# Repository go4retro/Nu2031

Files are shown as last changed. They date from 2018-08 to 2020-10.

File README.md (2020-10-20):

# Nu2031 

This adapter allows one to utilize a Commodore 1541 disk drive as both a serial disk drive for the serial IEC-based Commodore computers (VIC-20, C64, +4, C16, C128, etc.) and also an IEEE-488 drive for the PET/CBM line of computer systems.

## Introduction

Nu2031 ("New" 2031, with new in quotes because it's not really new :-)) comprises a two part hardware modification for the Commodore 1541 disk drive.  The first part is a 6522 Versatile Interface Adapter (VIA) daughterboard that dynamically switches specific VIA signals between the existing 1541 serial IEC port and an on-board IEEE-488 interface. The second part is a special multi-bank ROM-el replacement ROM that contains both the original 1541 DOS and a patched DOS that will enable the 1541 drive to function as a IEEE-488 CBM 2031 workalike drive. Using a single switch, connected to both adapter boards, the system can be quickly switched from one interface to the other.

This design is a refinement of many previous conversion projects, listed below:

The original (and largest, in my opinion) effort was included in an old 64'er magazine article.  Andre Fachat, who built the original interface, re-created the schematic and re-typed in the DOS patching utility, which are available at  http://www.6502.org/users/andre/cbmhw/ieee488/index.html. 

Dirk Wouters improved on the design by allowing the conversion to be "switched off", allowing continued use of the 1541 as a 1541 drive while supporting the IEEE-488 functionality.  Though his plans are no longer available, the project is discussed at https://www.lemon64.com/forum/viewtopic.php?t=71124 and at https://www.forum64.de/index.php?thread/91569-1541-to-ieee488-trimod-adapter/ (German).

Nu2031 was started before Dirk's project was presented, so it does not borrow from that design, though the two projects share a common set of functionality.

## Technical Details

The heart of the unit is the main adapter PCB (the ROM board is just a simple multi-bank ROM). The PCB contains both the 75160 and 75161 IEEE-488 interface ICs, as well as a Xilinx XC9572XL Complex Programmable Logic Device (CPLD).  Unlike the initial 64'er/Andre Fachat project, which simply wired the VIC to the interface ICs, or Dirk Wouter's interface, which uses banks of quad bilateral CMOS 4066 bilateral switches to connect or disconnect the various VIA signals to the 1541 motherboard or the IEEE 488 bus transceivers, this design implements the various IEEE-488 signal directions, as noted on page 2 of the 75161B datasheet (https://www.ti.com/lit/gpn/sn75161b). For reference, DC is always 'H' (5V), so the truth table can be somewhat simplified. The  ROM select signal noth only chooses which ROM bank to use, but is also used by the design to select which interface to enable.  The deselected interface is configured to allow other devices to continue to function on the de-selected bus.

If the system sees the ROM select signal change state, the interface immediately reconfigures the interface connects and resets the drive so the correct ROM will be initialized.

## Future Directions:

- Support method to "softswitch" the interface from one bus to another.

## License
Copyright (C) 2019-20  RETRO Innovations

These files are free designs; you can redistribute them and/or modify
them under the terms of the Creative Commons Attribution-ShareAlike 
4.0 International License.

You should have received a copy of the license along with this
work. If not, see <http://creativecommons.org/licenses/by-sa/4.0/>.

These files are distributed in the hope that they will be useful,
but WITHOUT ANY WARRANTY; without even the implied warranty of
MERCHANTABILITY or FITNESS FOR A PARTICULAR PURPOSE.  See the
license for more details.

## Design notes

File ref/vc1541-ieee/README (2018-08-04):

This is the description of the IEEE488 interface published in the
German 64er magazin a long time ago. It is basically modelled
after the 2031 schematics, the IEEE488 sister drive to the VC1541.

Code to patch the VC1541 ROM is provided. The original 2031 ROM
is different in both ROM chips, but the patch manages to get the
changes into one ROM chip only.

A. Fachat

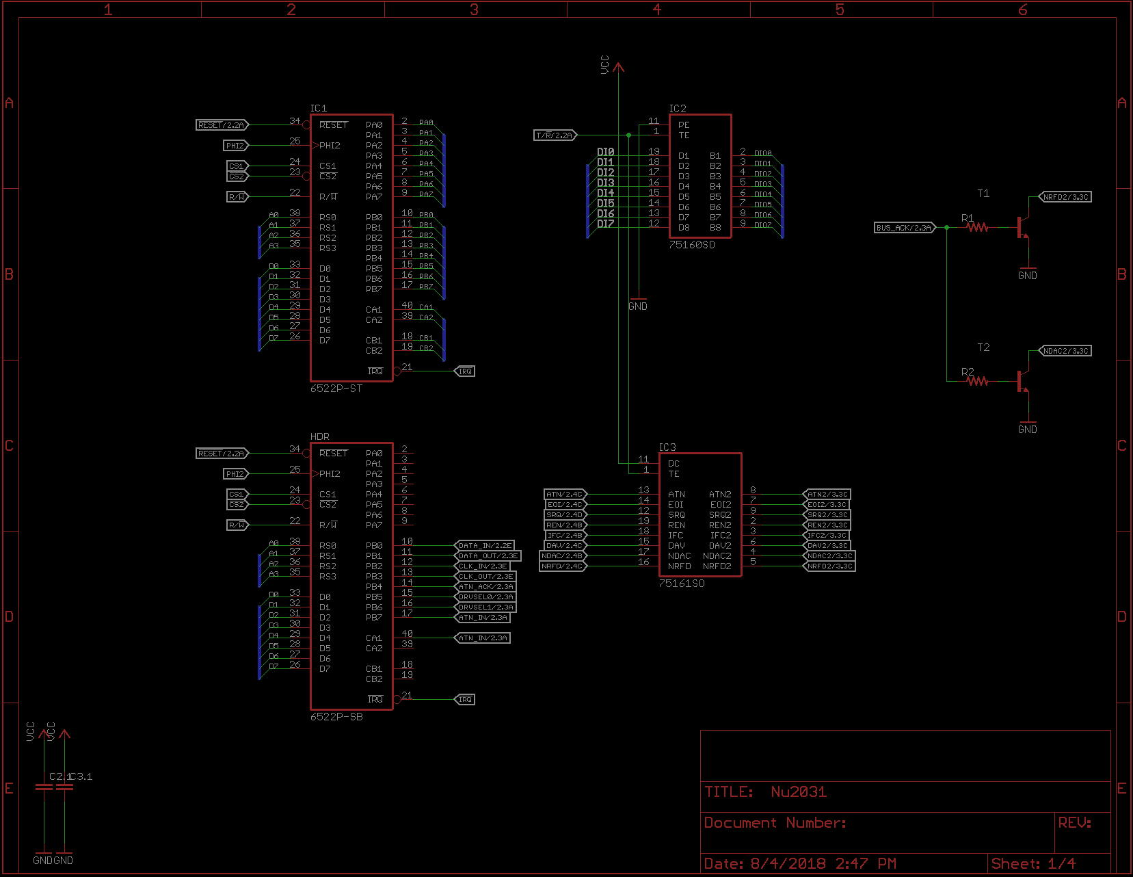
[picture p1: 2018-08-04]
pcb/Nu2031 Schematic.png

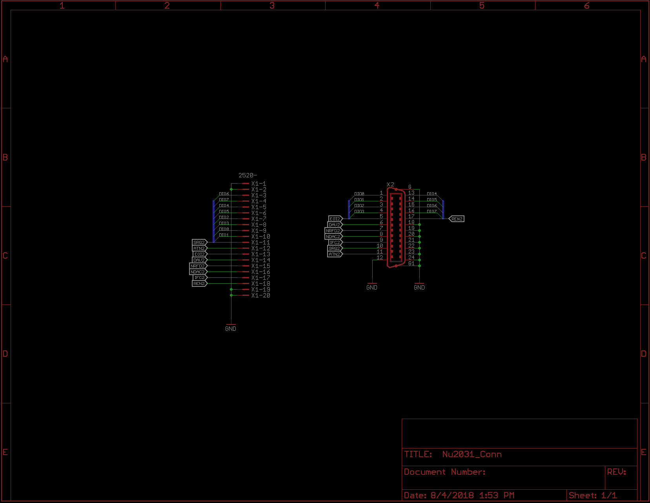
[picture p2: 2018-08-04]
pcb/Nu2031_Conn Schematic.png

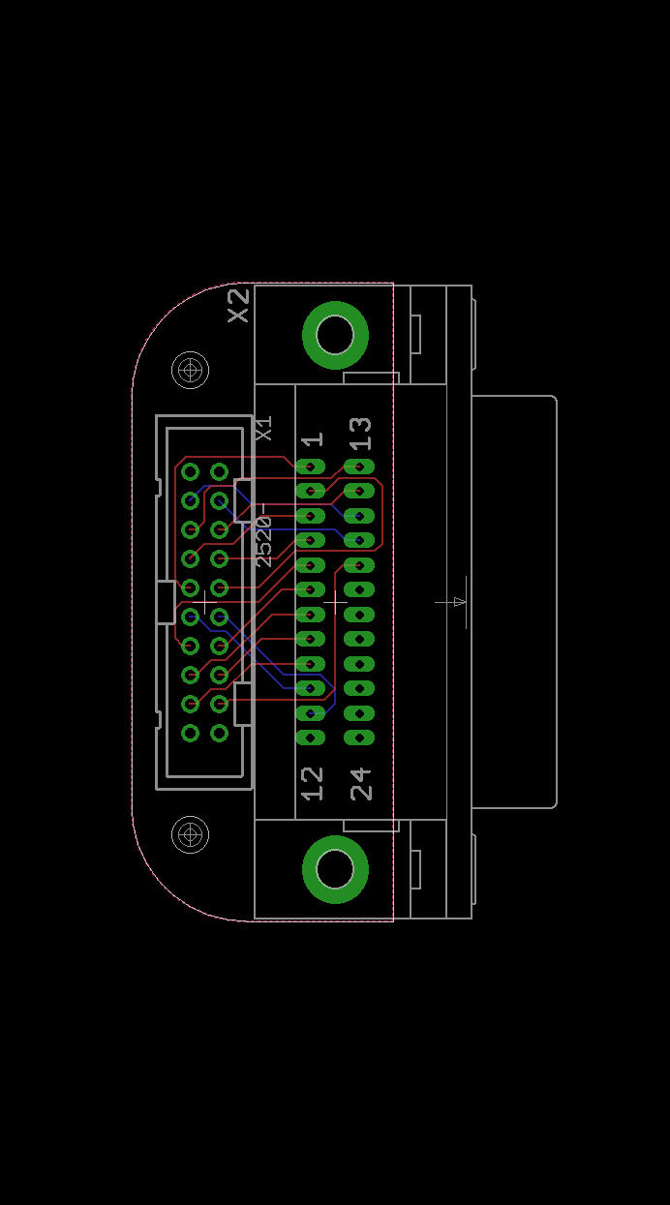
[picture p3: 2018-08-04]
pcb/Nu2031_Conn PCB.png

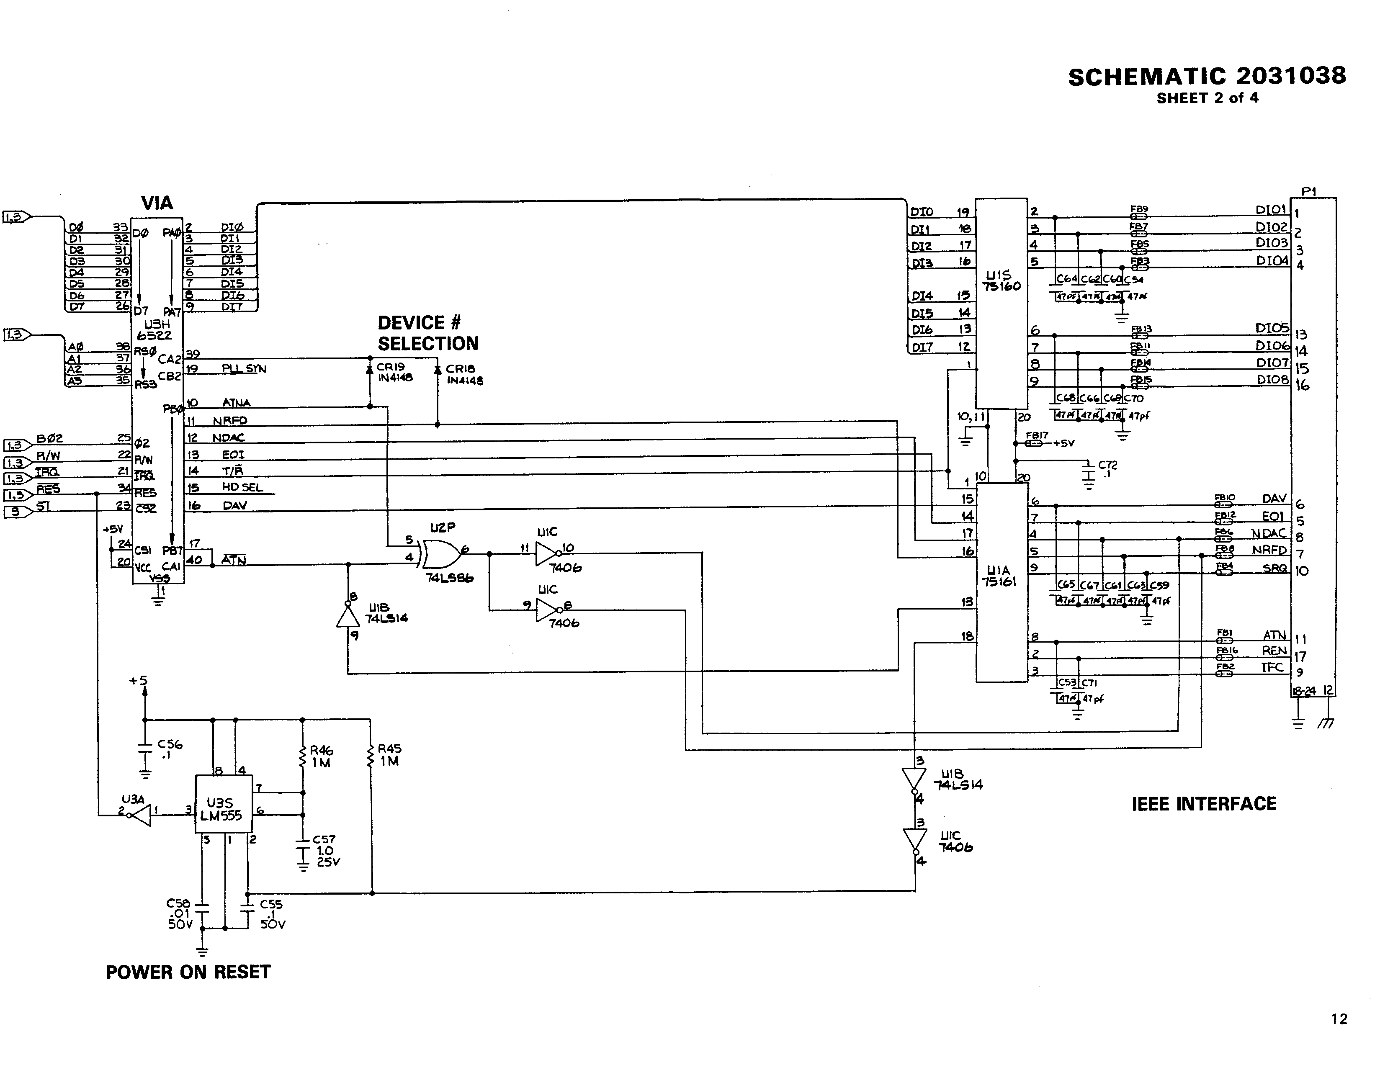
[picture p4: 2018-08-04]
ref/page-12r.gif

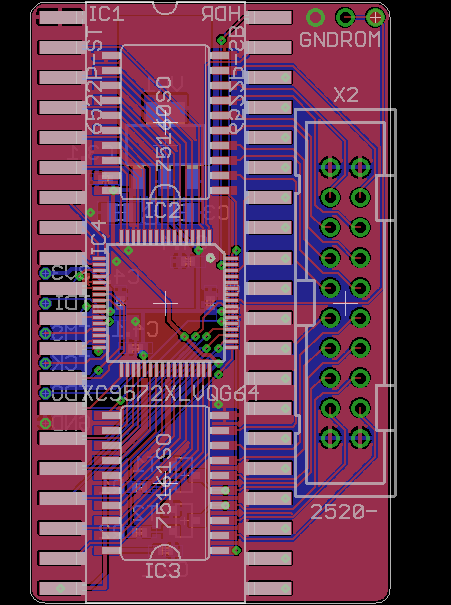
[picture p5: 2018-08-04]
pcb/Nu2031 PCB (ground pour).png

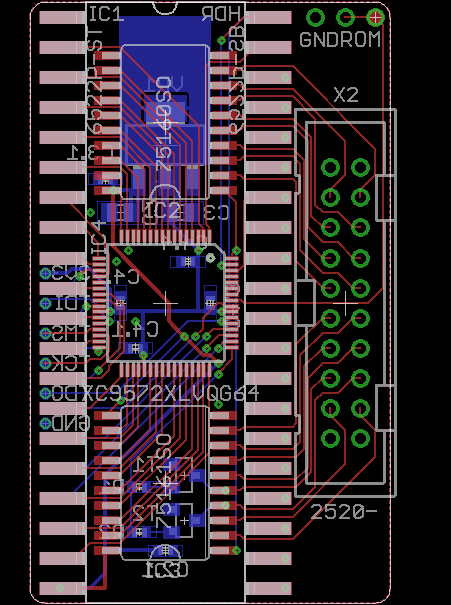
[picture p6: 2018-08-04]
pcb/Nu2031 PCB.png

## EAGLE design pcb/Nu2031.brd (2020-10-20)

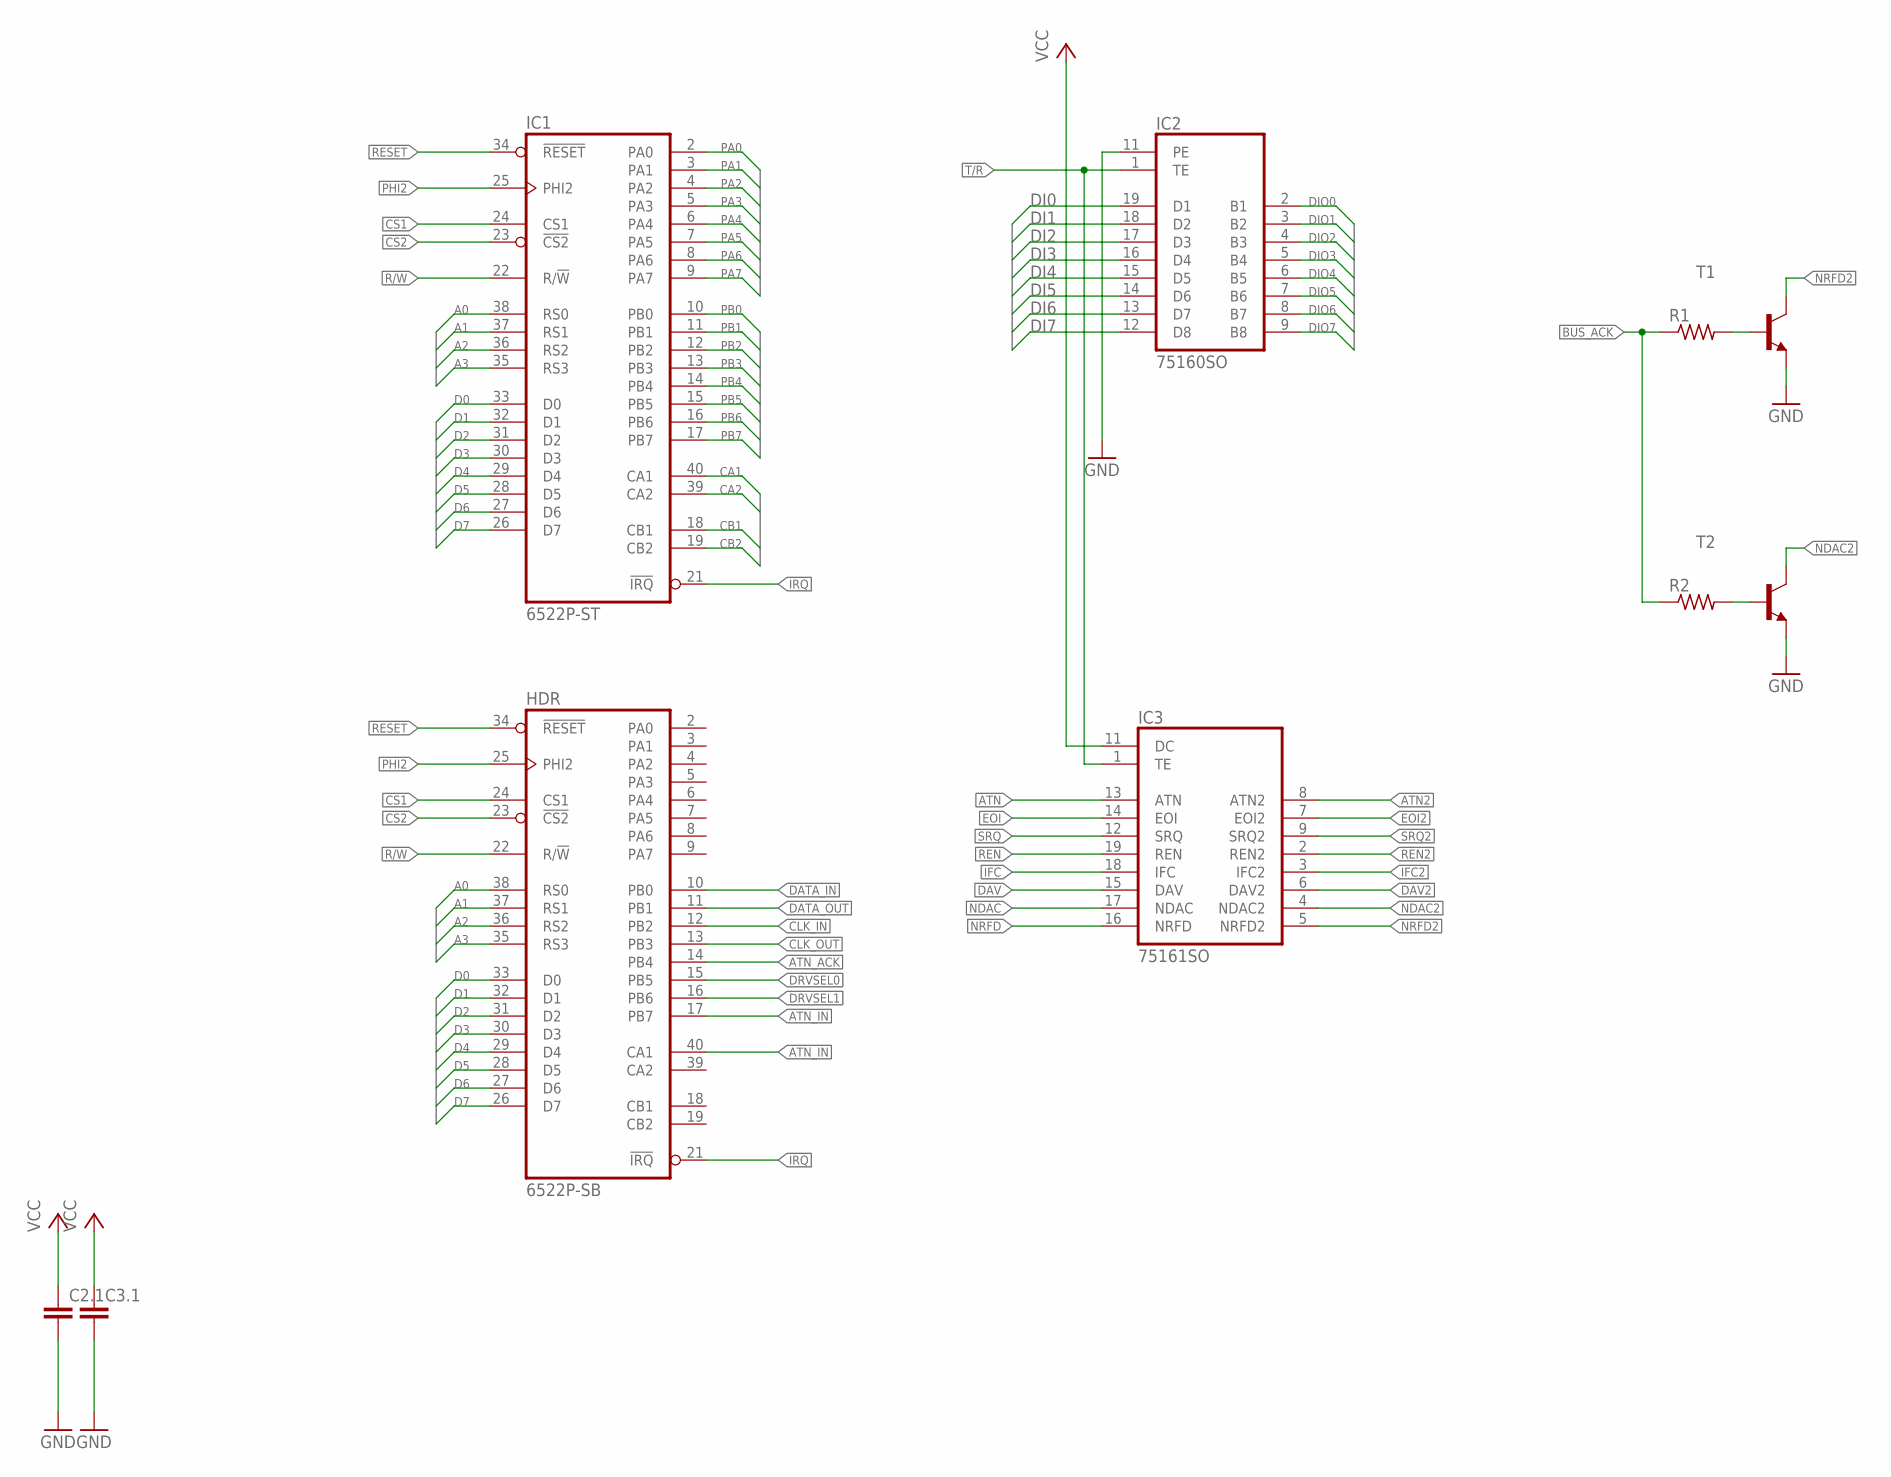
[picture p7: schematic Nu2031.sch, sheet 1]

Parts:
C2.1, C3.1: C-EUC0402; C0402
HDR: 6522P-SB; DIL40-SMD-REVERSE
IC1: 6522P-ST; DIL40-SMD
IC2: 75160SO; SO20L
IC3: 75161SO; SO20L
R1, R2: R-US_R0402; R0402
T1, T2: MMBT3904LT1-NPN-SOT23-BEC; SOT23-BEC

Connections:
!CS2: HDR.23 (!CS2), IC1.23 (!CS2)
!IRQ: HDR.21 (!IRQ), IC1.21 (!IRQ)
!RESET: HDR.34 (!RESET), IC1.34 (!RESET); also elsewhere on the board
A0: HDR.38 (RS0), IC1.38 (RS0)
A1: HDR.37 (RS1), IC1.37 (RS1)
A2: HDR.36 (RS2), IC1.36 (RS2)
A3: HDR.35 (RS3), IC1.35 (RS3)
ATN: IC3.13 (ATN); also elsewhere on the board
ATN2: IC3.8 (ATN2); also elsewhere on the board
ATN_ACK: HDR.14 (PB4); also elsewhere on the board
ATN_IN: HDR.17 (PB7), HDR.40 (CA1); also elsewhere on the board
BUS_ACK: R1.1, R2.1; also elsewhere on the board
CA1: IC1.40 (CA1); also elsewhere on the board
CA2: IC1.39 (CA2); also elsewhere on the board
CB1: IC1.18 (CB1); also elsewhere on the board
CB2: IC1.19 (CB2); also elsewhere on the board
CLK_IN: HDR.12 (PB2); also elsewhere on the board
CLK_OUT: HDR.13 (PB3); also elsewhere on the board
CS1: HDR.24 (CS1), IC1.24 (CS1)
D0: HDR.33 (D0), IC1.33 (D0)
D1: HDR.32 (D1), IC1.32 (D1)
D2: HDR.31 (D2), IC1.31 (D2)
D3: HDR.30 (D3), IC1.30 (D3)
D4: HDR.29 (D4), IC1.29 (D4)
D5: HDR.28 (D5), IC1.28 (D5)
D6: HDR.27 (D6), IC1.27 (D6)
D7: HDR.26 (D7), IC1.26 (D7)
DATA_IN: HDR.10 (PB0); also elsewhere on the board
DATA_OUT: HDR.11 (PB1); also elsewhere on the board
DAV: IC3.15 (DAV); also elsewhere on the board
DAV2: IC3.6 (DAV2); also elsewhere on the board
DI0: IC2.19 (D1); also elsewhere on the board
DI1: IC2.18 (D2); also elsewhere on the board
DI2: IC2.17 (D3); also elsewhere on the board
DI3: IC2.16 (D4); also elsewhere on the board
DI4: IC2.15 (D5); also elsewhere on the board
DI5: IC2.14 (D6); also elsewhere on the board
DI6: IC2.13 (D7); also elsewhere on the board
DI7: IC2.12 (D8); also elsewhere on the board
DIO0: IC2.2 (B1); also elsewhere on the board
DIO1: IC2.3 (B2); also elsewhere on the board
DIO2: IC2.4 (B3); also elsewhere on the board
DIO3: IC2.5 (B4); also elsewhere on the board
DIO4: IC2.6 (B5); also elsewhere on the board
DIO5: IC2.7 (B6); also elsewhere on the board
DIO6: IC2.8 (B7); also elsewhere on the board
DIO7: IC2.9 (B8); also elsewhere on the board
DRVSEL0: HDR.15 (PB5); also elsewhere on the board
DRVSEL1: HDR.16 (PB6); also elsewhere on the board
EOI: IC3.14 (EOI); also elsewhere on the board
EOI2: IC3.7 (EOI2); also elsewhere on the board
GND: C2.1.2, C3.1.2, HDR.1 (GND), IC1.1 (GND), IC2.10 (GND), IC2.11 (PE), IC3.10 (GND), T1.E, T2.E; also elsewhere on the board
IFC: IC3.18 (IFC); also elsewhere on the board
IFC2: IC3.3 (IFC2); also elsewhere on the board
unnamed: R1.2, T1.B
unnamed: R2.2, T2.B
NDAC: IC3.17 (NDAC); also elsewhere on the board
NDAC2: IC3.4 (NDAC2), T2.C; also elsewhere on the board
NRFD: IC3.16 (NRFD); also elsewhere on the board
NRFD2: IC3.5 (NRFD2), T1.C; also elsewhere on the board
PA0: IC1.2 (PA0); also elsewhere on the board
PA1: IC1.3 (PA1); also elsewhere on the board
PA2: IC1.4 (PA2); also elsewhere on the board
PA3: IC1.5 (PA3); also elsewhere on the board
PA4: IC1.6 (PA4); also elsewhere on the board
PA5: IC1.7 (PA5); also elsewhere on the board
PA6: IC1.8 (PA6); also elsewhere on the board
PA7: IC1.9 (PA7); also elsewhere on the board
PB0: IC1.10 (PB0); also elsewhere on the board
PB1: IC1.11 (PB1); also elsewhere on the board
PB2: IC1.12 (PB2); also elsewhere on the board
PB3: IC1.13 (PB3); also elsewhere on the board
PB4: IC1.14 (PB4); also elsewhere on the board
PB5: IC1.15 (PB5); also elsewhere on the board
PB6: IC1.16 (PB6); also elsewhere on the board
PB7: IC1.17 (PB7); also elsewhere on the board
PHI2: HDR.25 (PHI2), IC1.25 (PHI2)
R/!W: HDR.22 (R/!W), IC1.22 (R/!W)
REN: IC3.19 (REN); also elsewhere on the board
REN2: IC3.2 (REN2); also elsewhere on the board
SRQ: IC3.12 (SRQ); also elsewhere on the board
SRQ2: IC3.9 (SRQ2); also elsewhere on the board
T/!R: IC2.1 (TE), IC3.1 (TE); also elsewhere on the board
VCC: C2.1.1, C3.1.1, HDR.20 (VCC), IC1.20 (VCC), IC2.20 (VCC), IC3.11 (DC), IC3.20 (VCC); also elsewhere on the board

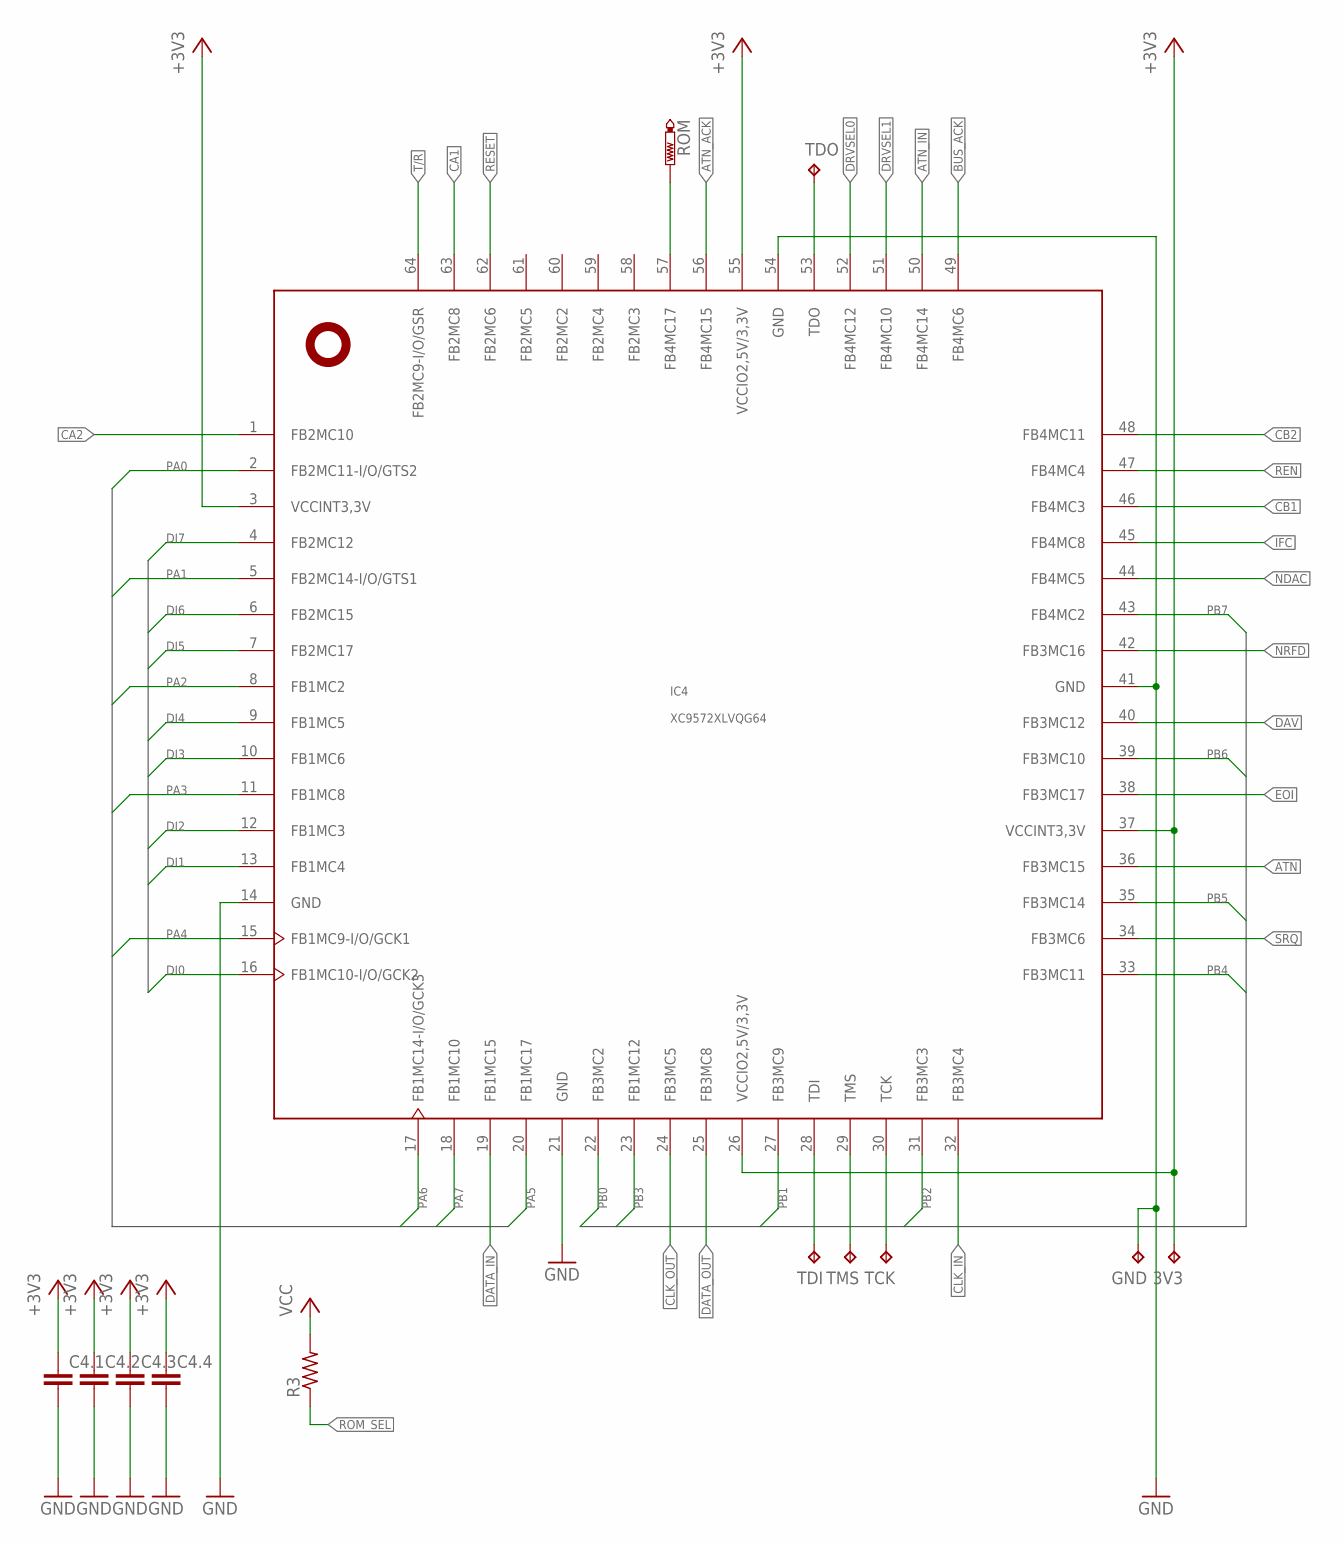
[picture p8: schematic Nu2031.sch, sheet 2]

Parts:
3V3: TPTP10R; TP10R
C4.1, C4.2, C4.3, C4.4: C-EUC0402; C0402
GND: TPTP10R; TP10R
IC4: XC9572XLVQG64; VQFP64
R3: R-US_R0402; R0402
ROM: PTR1B1,27; B1,27
TCK: TPTP10R; TP10R
TDI: TPTP10R; TP10R
TDO: TPTP10R; TP10R
TMS: TPTP10R; TP10R

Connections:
!RESET: IC4.62 (FB2MC6); also elsewhere on the board
+3V3: 3V3.TP, C4.1.1, C4.2.1, C4.3.1, C4.4.1, IC4.3 (VCCINT3,3V), IC4.26 (VCCIO2,5V/3,3V), IC4.37 (VCCINT3,3V), IC4.55 (VCCIO2,5V/3,3V); also elsewhere on the board
ATN: IC4.36 (FB3MC15); also elsewhere on the board
ATN_ACK: IC4.56 (FB4MC15); also elsewhere on the board
ATN_IN: IC4.50 (FB4MC14); also elsewhere on the board
BUS_ACK: IC4.49 (FB4MC6); also elsewhere on the board
CA1: IC4.63 (FB2MC8); also elsewhere on the board
CA2: IC4.1 (FB2MC10); also elsewhere on the board
CB1: IC4.46 (FB4MC3); also elsewhere on the board
CB2: IC4.48 (FB4MC11); also elsewhere on the board
CLK_IN: IC4.32 (FB3MC4); also elsewhere on the board
CLK_OUT: IC4.24 (FB3MC5); also elsewhere on the board
DATA_IN: IC4.19 (FB1MC15); also elsewhere on the board
DATA_OUT: IC4.25 (FB3MC8); also elsewhere on the board
DAV: IC4.40 (FB3MC12); also elsewhere on the board
DI0: IC4.16 (FB1MC10-I/O/GCK2); also elsewhere on the board
DI1: IC4.13 (FB1MC4); also elsewhere on the board
DI2: IC4.12 (FB1MC3); also elsewhere on the board
DI3: IC4.10 (FB1MC6); also elsewhere on the board
DI4: IC4.9 (FB1MC5); also elsewhere on the board
DI5: IC4.7 (FB2MC17); also elsewhere on the board
DI6: IC4.6 (FB2MC15); also elsewhere on the board
DI7: IC4.4 (FB2MC12); also elsewhere on the board
DRVSEL0: IC4.52 (FB4MC12); also elsewhere on the board
DRVSEL1: IC4.51 (FB4MC10); also elsewhere on the board
EOI: IC4.38 (FB3MC17); also elsewhere on the board
GND: C4.1.2, C4.2.2, C4.3.2, C4.4.2, GND.TP, IC4.14 (GND), IC4.21 (GND), IC4.41 (GND), IC4.54 (GND); also elsewhere on the board
IFC: IC4.45 (FB4MC8); also elsewhere on the board
NDAC: IC4.44 (FB4MC5); also elsewhere on the board
NRFD: IC4.42 (FB3MC16); also elsewhere on the board
PA0: IC4.2 (FB2MC11-I/O/GTS2); also elsewhere on the board
PA1: IC4.5 (FB2MC14-I/O/GTS1); also elsewhere on the board
PA2: IC4.8 (FB1MC2); also elsewhere on the board
PA3: IC4.11 (FB1MC8); also elsewhere on the board
PA4: IC4.15 (FB1MC9-I/O/GCK1); also elsewhere on the board
PA5: IC4.20 (FB1MC17); also elsewhere on the board
PA6: IC4.17 (FB1MC14-I/O/GCK3); also elsewhere on the board
PA7: IC4.18 (FB1MC10); also elsewhere on the board
PB0: IC4.22 (FB3MC2); also elsewhere on the board
PB1: IC4.27 (FB3MC9); also elsewhere on the board
PB2: IC4.31 (FB3MC3); also elsewhere on the board
PB3: IC4.23 (FB1MC12); also elsewhere on the board
PB4: IC4.33 (FB3MC11); also elsewhere on the board
PB5: IC4.35 (FB3MC14); also elsewhere on the board
PB6: IC4.39 (FB3MC10); also elsewhere on the board
PB7: IC4.43 (FB4MC2); also elsewhere on the board
REN: IC4.47 (FB4MC4); also elsewhere on the board
ROM_SEL: IC4.57 (FB4MC17), R3.1, ROM.TP
SRQ: IC4.34 (FB3MC6); also elsewhere on the board
T/!R: IC4.64 (FB2MC9-I/O/GSR); also elsewhere on the board
TCK: IC4.30 (TCK), TCK.TP
TDI: IC4.28 (TDI), TDI.TP
TDO: IC4.53 (TDO), TDO.TP
TMS: IC4.29 (TMS), TMS.TP
VCC: R3.2; also elsewhere on the board

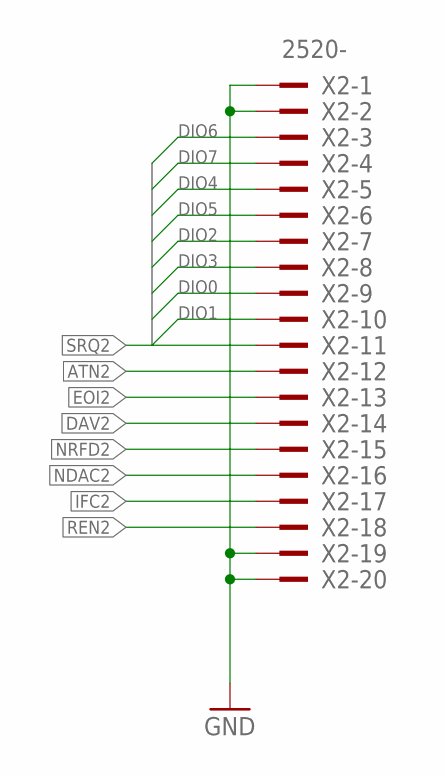
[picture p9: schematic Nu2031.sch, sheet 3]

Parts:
X2: 2520-; PAK100/2500-20

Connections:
ATN2: X2.12; also elsewhere on the board
DAV2: X2.14; also elsewhere on the board
DIO0: X2.9; also elsewhere on the board
DIO1: X2.10; also elsewhere on the board
DIO2: X2.7; also elsewhere on the board
DIO3: X2.8; also elsewhere on the board
DIO4: X2.5; also elsewhere on the board
DIO5: X2.6; also elsewhere on the board
DIO6: X2.3; also elsewhere on the board
DIO7: X2.4; also elsewhere on the board
EOI2: X2.13; also elsewhere on the board
GND: X2.1, X2.2, X2.19, X2.20; also elsewhere on the board
IFC2: X2.17; also elsewhere on the board
NDAC2: X2.16; also elsewhere on the board
NRFD2: X2.15; also elsewhere on the board
REN2: X2.18; also elsewhere on the board
SRQ2: X2.11; also elsewhere on the board

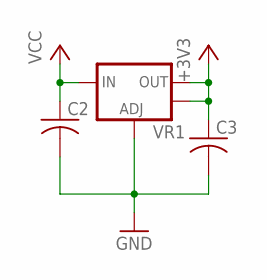
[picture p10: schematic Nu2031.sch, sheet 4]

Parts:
C2, C3: C-USC0805; C0805
VR1: V_REG_LM1117SOT223; SOT223

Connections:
+3V3: C3.1, VR1.2 (OUT), VR1.4 (OUT); also elsewhere on the board
GND: C2.2, C3.2, VR1.1 (ADJ); also elsewhere on the board
VCC: C2.1, VR1.3 (IN); also elsewhere on the board

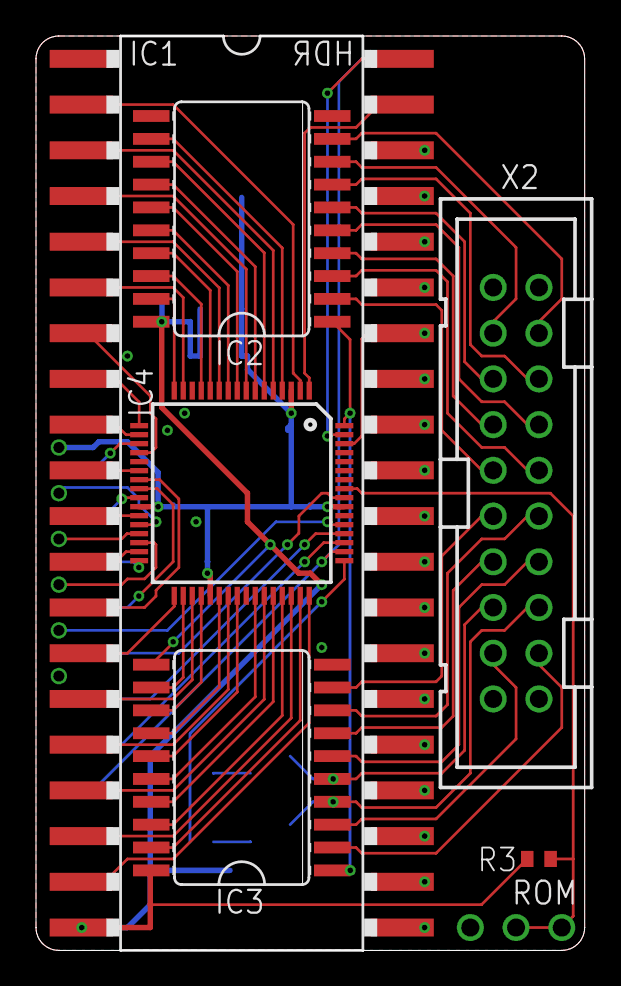
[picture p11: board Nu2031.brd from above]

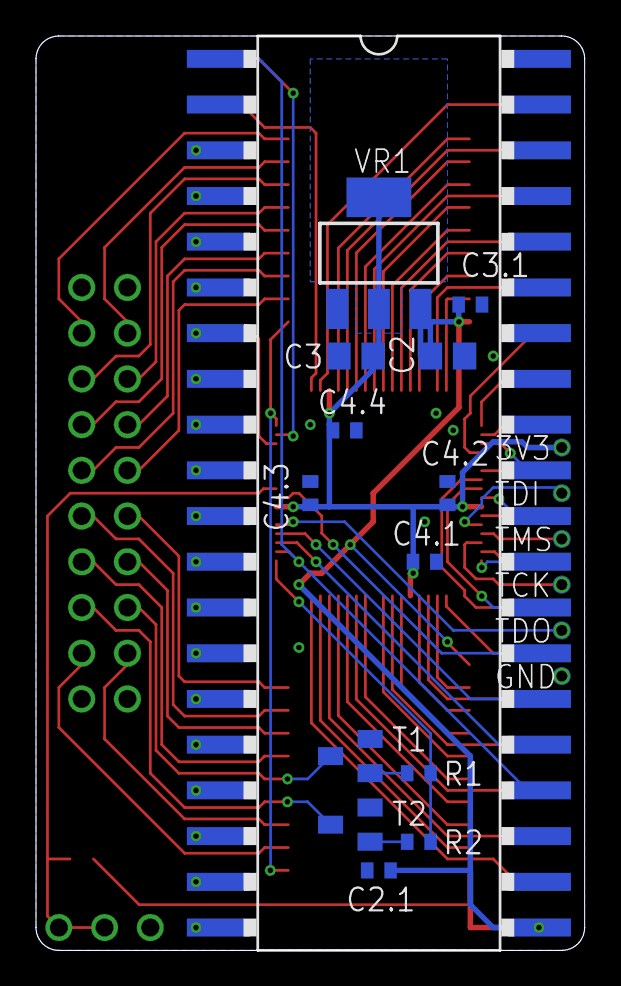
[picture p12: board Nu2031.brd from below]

Board: 2 copper layers, 30.5 x 50.8 mm, 27 parts (19 on the bottom side), 90 nets.

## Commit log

2018-08-04 Added schematic PNGs
2020-10-19 First working config
    * Fix some of the IEEE logic in HDL
    * Add resistor to ROM selection, to default to IEC
    * Add patched 1541 (2031-ish) DOS
    [Nu2031.brd, Nu2031.sch, Nu2031_Conn.brd]
2020-10-20 Implement auto-reset functionality and clean up Verilog a bit.
    [Nu2031.brd]

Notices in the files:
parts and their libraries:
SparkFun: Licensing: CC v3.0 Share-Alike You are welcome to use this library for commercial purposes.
